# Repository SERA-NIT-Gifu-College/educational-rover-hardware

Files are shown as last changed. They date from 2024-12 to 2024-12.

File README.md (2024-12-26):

# educational-rover-hardware

教育用ローバーのハードウェア仕様

オンボードコンピューターにRaspberry Pi Zero/Wを使用した教育用ローバーの設計書です。

## ピン配置

### DRV8835 (Motor Driver)

| Part/Leg | Raspberry Pi GPIO |
| --- | --- |
| AIN1 | 18 |
| AIN2 | 23 |
| BIN1 | 24 |
| BIN2 | 25 |

### SSD1306 (OLED Display)

| Part/Leg | Raspberry Pi GPIO |
| --- | --- |
| SDA | 2 |
| SCL | 3 |
| VCC | 1 |
| GND | (GND) |

### BMX055 (9 Axes Sensor)

| Part/Leg | Raspberry Pi GPIO |
| --- | --- |
| SDA | 2 |
| SCL | 3 |
| VCC | 1 |
| VCCIO | X |
| 3V3 | 1 |
| GND | (GND) |

### LEDs

| Part/Leg | Raspberry Pi GPIO |
| --- | --- |
| LED1 | 16 |
| LED2 | 20 |
| LED3 | 21 |

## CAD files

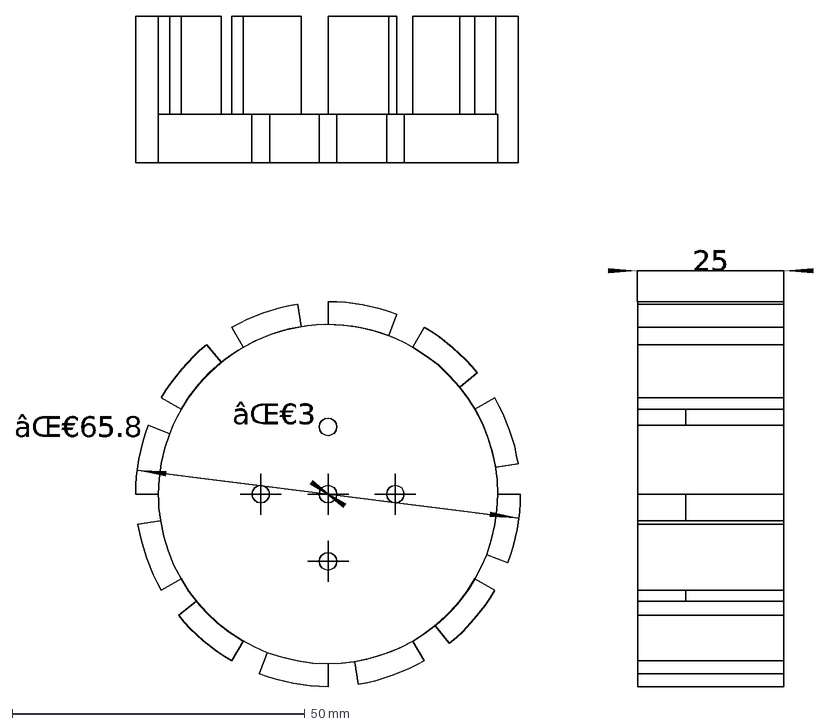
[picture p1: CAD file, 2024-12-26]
3dmodels/wheel-drawing.dxf
âŒ€3
âŒ€65.8
25

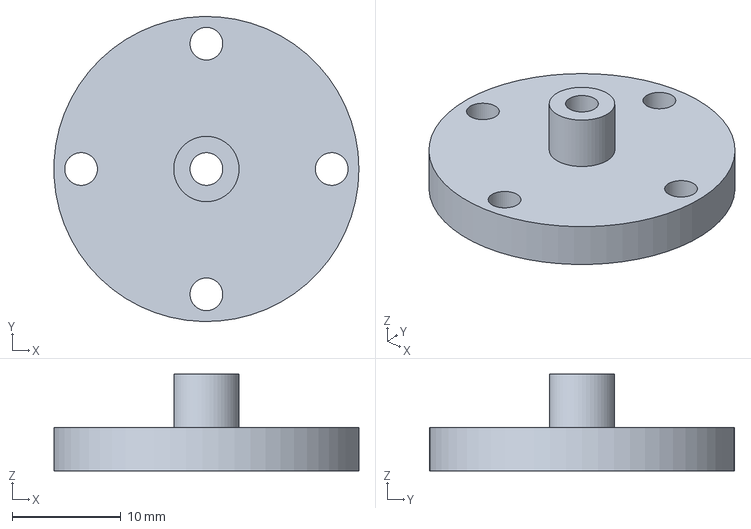
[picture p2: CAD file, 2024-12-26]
3dmodels/connector.FCStd
28.0 x 28.0 x 8.90 mm

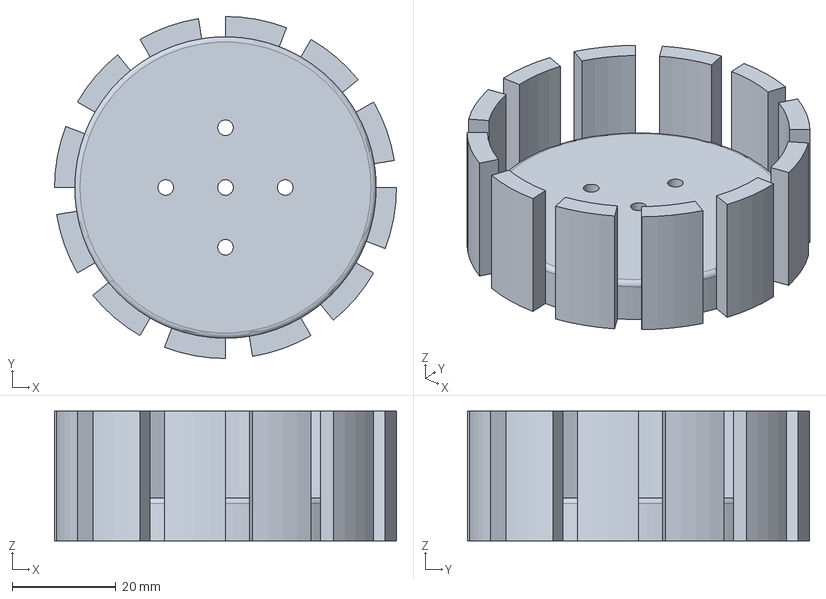
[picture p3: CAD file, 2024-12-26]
3dmodels/wheel.FCStd
65.8 x 65.8 x 25.0 mm

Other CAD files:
3dmodels/STLs/connector.stl
3dmodels/STLs/wheel.stl

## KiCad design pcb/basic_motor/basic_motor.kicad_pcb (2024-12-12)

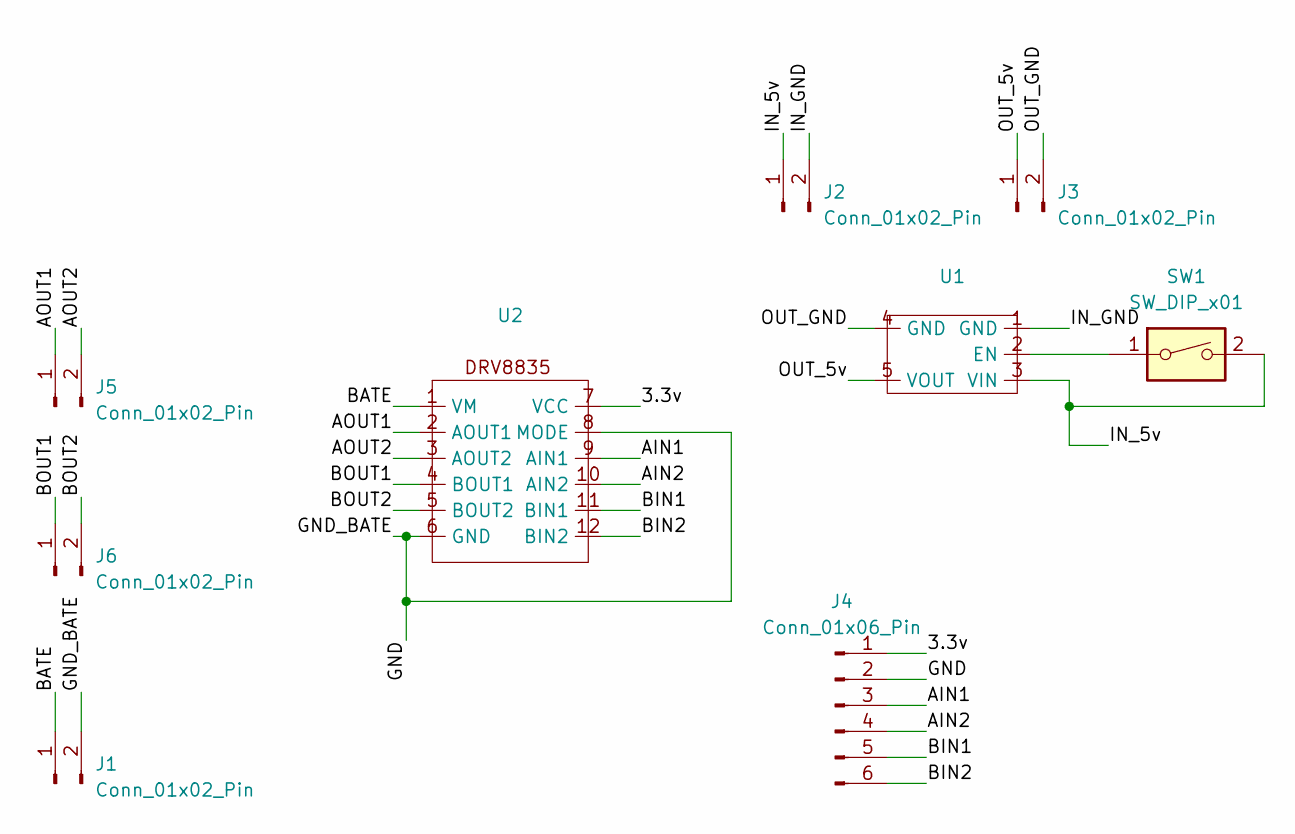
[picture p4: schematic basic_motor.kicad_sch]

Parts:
J1, J2: Conn_01x02_Pin; JST_PH_S2B-PH-K_1x02_P2.00mm_Horizontal
J3: Conn_01x02_Pin; PinHeader_1x02_P2.54mm_Horizontal
J4: Conn_01x06_Pin; PinHeader_1x06_P2.54mm_Horizontal
J5, J6: Conn_01x02_Pin; PinHeader_1x02_P2.54mm_Vertical
SW1: SW_DIP_x01; SWITCH
U1: TPS61230A
U2: DRV8835

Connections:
/3.3v: J4.1, U2.7 (VCC)
/AIN1: J4.3, U2.9 (AIN1)
/AIN2: J4.4, U2.10 (AIN2)
/AOUT1: J5.1, U2.2 (AOUT1)
/AOUT2: J5.2, U2.3 (AOUT2)
/BATE: J1.1, U2.1 (VM)
/BIN1: J4.5, U2.11 (BIN1)
/BIN2: J4.6, U2.12 (BIN2)
/BOUT1: J6.1, U2.4 (BOUT1)
/BOUT2: J6.2, U2.5 (BOUT2)
/GND: J1.2, J4.2, U2.6 (GND), U2.8 (MODE)
/IN_5v: J2.1, SW1.2, U1.3 (VIN)
/IN_GND: J2.2, U1.1 (GND)
/OUT_5v: J3.1, U1.5 (VOUT)
/OUT_GND: J3.2, U1.4 (GND)
unnamed: SW1.1, U1.2 (EN)

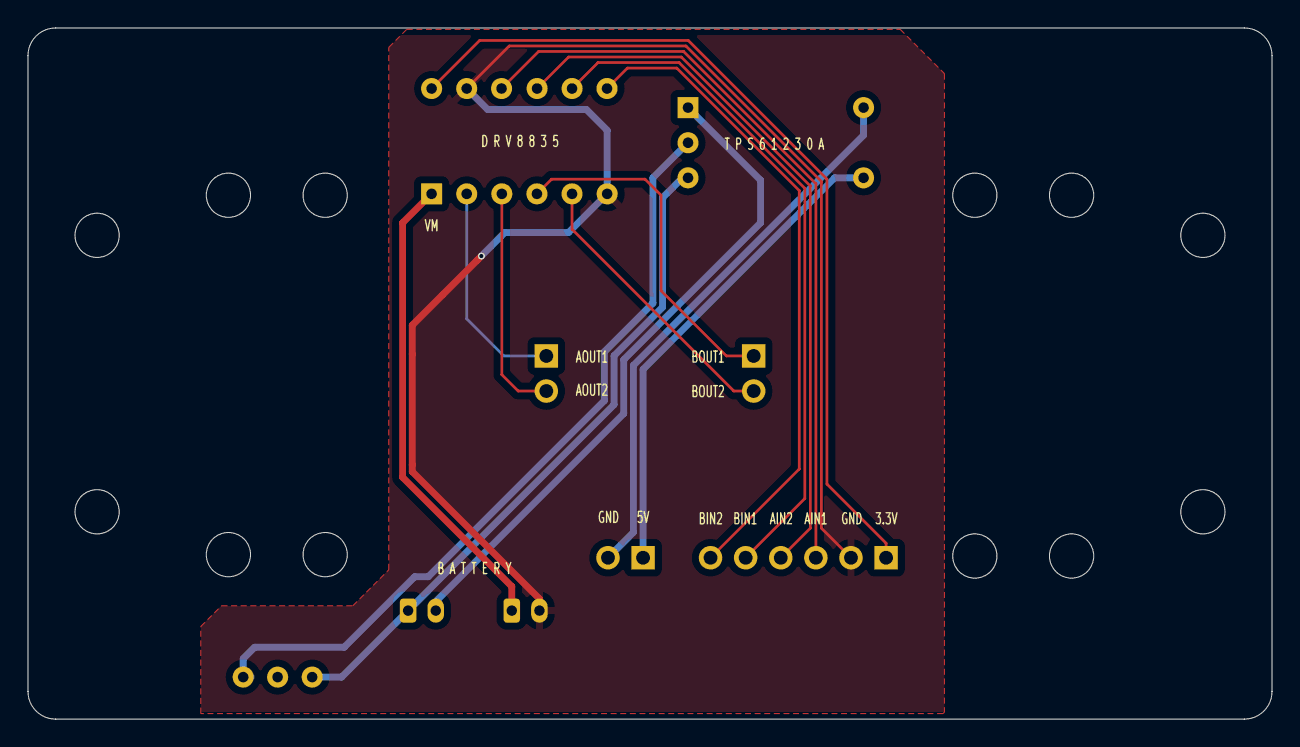
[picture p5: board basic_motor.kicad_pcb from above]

Board: 2 copper layers, 90.0 x 50.0 mm, 9 parts (0 on the bottom side), 16 nets.

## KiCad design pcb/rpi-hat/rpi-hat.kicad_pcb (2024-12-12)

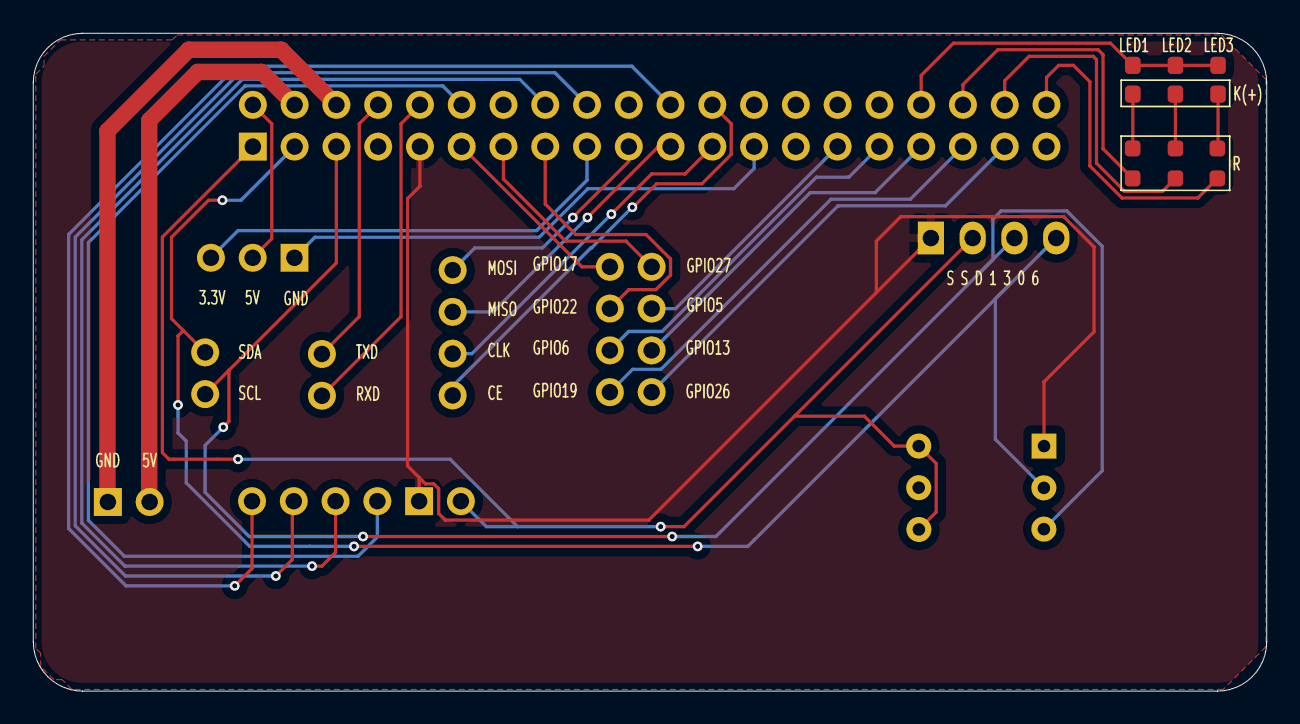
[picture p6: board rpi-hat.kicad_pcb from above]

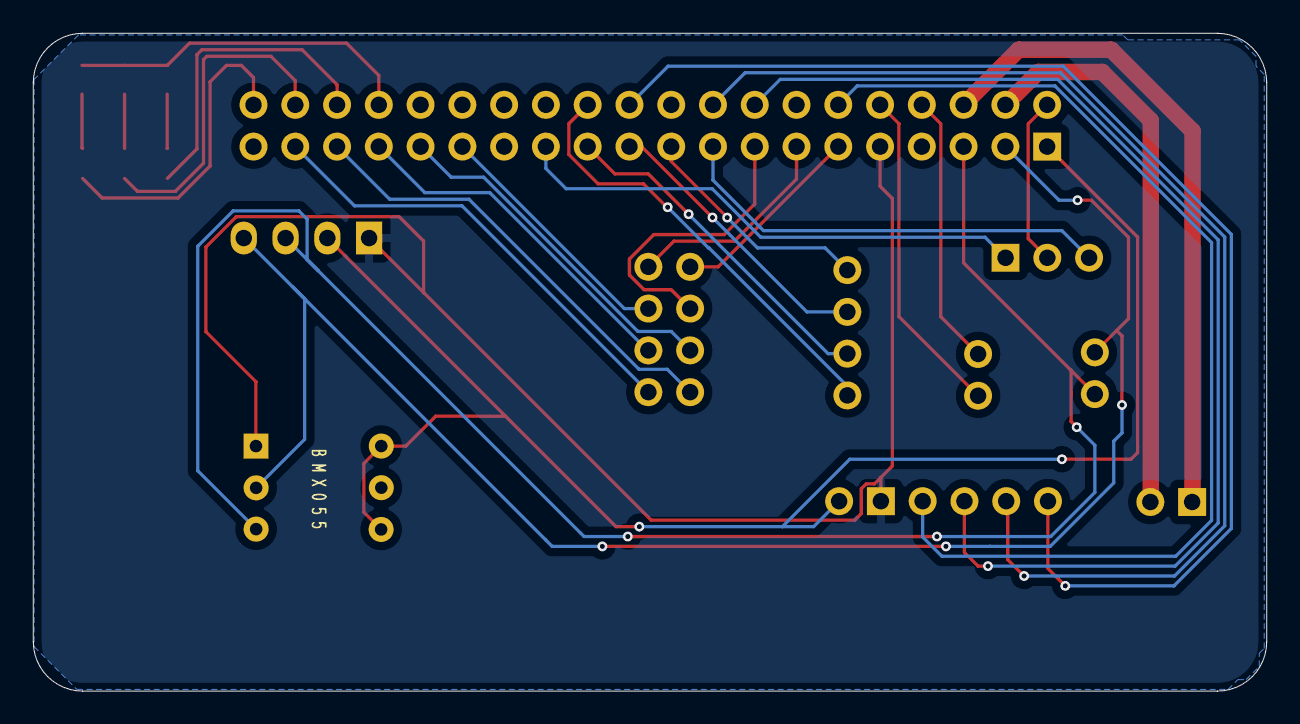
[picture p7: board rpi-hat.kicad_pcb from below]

Board: 2 copper layers, 75.0 x 40.0 mm, 16 parts (4 on the bottom side), 34 nets.

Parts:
BMX055: BMX055
Brd1: SSD1306; 128x64OLED
D1, D2, D3: LED; LED_0603_1608Metric_Pad1.05x0.95mm_HandSolder
J1, J3, J4: Conn_01x02_Pin; PinHeader_1x02_P2.54mm_Vertical
J2: Conn_01x06_Pin; PinHeader_1x06_P2.54mm_Vertical
J5: Conn_01x03_Pin; PinHeader_1x03_P2.54mm_Vertical
J6: Conn_01x04_Pin; PinHeader_1x04_P2.54mm_Vertical
J7: Conn_01x08_Pin; PinHeader_2x04_P2.54mm_Vertical
R1, R2, R3: R; R_0603_1608Metric_Pad0.98x0.95mm_HandSolder
u1: PinSocket_2x20_P2.54mm_Vertical

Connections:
/3.3V_OUT: J5.1, u1.17 (3.3v)
/5V_OUT: J5.2, u1.2 (5v)
/5v_IN: J1.1, u1.4 (5v)
/AIN1: J2.4, u1.12 (GPIO18)
/AIN2: J2.3, u1.16 (GPIO23)
/BIN1: J2.2, u1.18 (GPIO24)
/BIN2: J2.1, u1.22 (GPIO25)
/CE: J6.4, u1.24 (GPIO8(CE0))
/CLK: J6.3, u1.23 (GPIO11(CLK))
/GND: Brd1.1 (GND), J2.5, u1.9 (GND)
/GND_IN: J1.2, u1.6 (GND)
/GND_LED: D1.2 (A), D2.2 (A), D3.2 (A), u1.34 (GND)
/GND_OUT: J5.3, u1.25 (GND)
/GP5: J7.4, u1.29 (GPIO5)
/GP6: J7.5, u1.31 (GPIO6)
/GP13: J7.6, u1.33 (GPIO13)
/GP17: J7.1, u1.11 (GPIO17)
/GP19: J7.7, u1.35 (GPIO19)
/GP22: J7.3, u1.15 (GPIO22)
/GP26: J7.8, u1.37 (GPIO26)
/GP27: J7.2, u1.13 (GPIO27)
/LED1: R1.2, u1.36 (GPIO16)
/LED2: R2.2, u1.38 (GPIO20)
/LED3: R3.2, u1.40 (GPIO21)
/MISO: J6.2, u1.21 (GPIO9(MISO))
/MOSI: J6.1, u1.19 (GPIO10(MOSI))
/RXD: J4.2, u1.10 (GPIO15(RXD))
/SCL: Brd1.3 (SCL), J3.2, u1.5 (GPIO3(SCL))
/SDA: Brd1.4 (SDA), J3.1, u1.3 (GPIO2(SDA))
/TXD: J4.1, u1.8 (GPIO14(TXD))
/VCC: Brd1.2 (VCC), J2.6, u1.1 (3.3v)
unnamed: D1.1 (K), R1.1
unnamed: D2.1 (K), R2.1
unnamed: D3.1 (K), R3.1

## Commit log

2024-12-12 Added PCBs
    [basic_motor-B_Cu.gbr, basic_motor-B_Mask.gbr, basic_motor-B_Paste.gbr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]
2024-12-26 Added 3D models, added parts on list
    [connector.FCStd, connector.stl, wheel-drawing.dxf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]
